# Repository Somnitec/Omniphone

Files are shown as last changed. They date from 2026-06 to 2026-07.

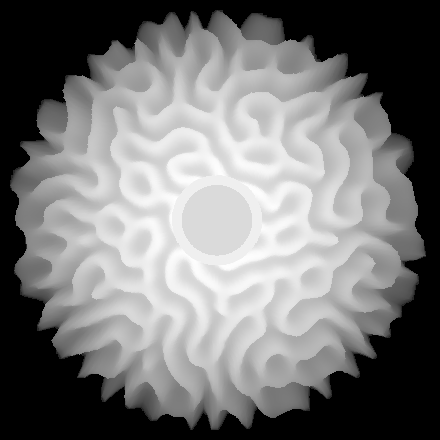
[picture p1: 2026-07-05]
3d-model/preview_flat_dome.png

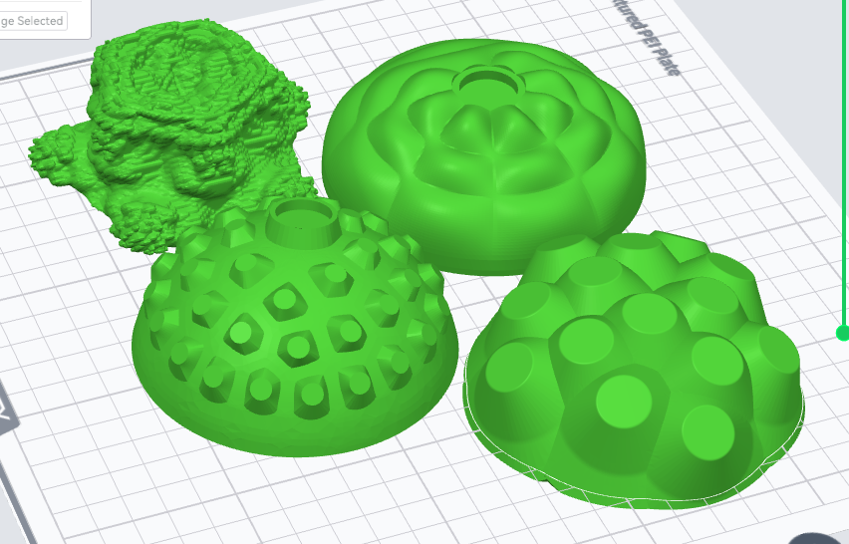
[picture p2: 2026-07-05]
3d-model/some first iterations.png

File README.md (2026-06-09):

# ◉ Omniphone
 
> *An instrument for everyone. Any shape. Any sound. Any player.*
 
---
 
The **Omniphone** is an open, tactile electronic instrument — built to be as expressive for a seasoned performer as it is immediate and joyful for someone touching it for the first time.
 
It started as a single idea. It grew into a collaboration. Now it's becoming a platform.
 
---
 
## ✦ Origin
 
The Omniphone was conceived and first built by **Arvid Jense**, as an experiment in what an electronic instrument could be if it didn't assume what a musician looks like.
 
It was developed further in close creative partnership with **Marie Caye** — shaping its philosophy of radical accessibility and shape language.
 
→ *Read the origin story and the thinking behind inclusive instrument design on [Create Digital Music](https://cdm.link/omniphone-inclusive-design-music-therapy/)*
 
---
 
## ✦ Now
 
The project continues under **Arvid Jense**, in active collaboration with **[SoundLab at Muziekgebouw aan 't IJ](https://www.muziekgebouw.nl)**.
 
This phase is about turning the Omniphone from a singular instrument into a **flexible platform**:
 
- 🔷 **Many shapes** — modular physical configurations for different bodies, contexts, and settings
- 🔊 **Many sounds** — a sonic engine that adapts to the musical world of each player
- 🎓 **Many players** — from children in workshops to professional performers on stage; from music therapists to noise artists
 
---
 
## ✦ What It Is
 
The Omniphone uses **capacitive touch sensing** to turn almost any surface into a playable instrument. No keys. No buttons. No prior musical knowledge required.
 
It is simultaneously:
- A **workshop instrument** — robust, inviting, immediately rewarding
- A **performance instrument** — expressive, precise, deeply configurable
- A **research platform** — for inclusive design, music therapy, and expanded musical interfaces
 
---
 
## ✦ Status
 
> 🚧 **Active development** — hardware and software in flux
 
Current focus:
- Capacitive sensing via MPR121
- LED feedback and expressive output mapping
- Platform architecture for multi-configuration support
 
---
 
## ✦ Code & Building

The firmware is a **PlatformIO monorepo**: every hardware configuration ("variant") lives in its own folder under [`variants/`](variants/) and is selected by a matching `[env:…]` in [`platformio.ini`](platformio.ini). Shared libraries (MPR121 driver, LCD driver) live in [`lib/`](lib/) and compile into every build; bring-up/diagnostic sketches live in [`test/`](test/).

### Variants

| `pio run -e …` | Board | Pads | Sensor | Audio | Notes |
|---|---|:----:|---|---|---|
| `pico-13pad` *(default)* | RPi Pico / RP2040 | 13 | MPR121 | Mozzi (I²S) | earlephilhower core |
| `esp32s3-19pad` | ESP32-S3 (LilyGO T8-S3) | 19 | 4× MPR121 | TBD | WiFi/OTA — capsense bring-up test (Teleplot + web view) |
| `teensy40-11pad` | Teensy 4.0  | 11 | MPR121 | Teensy Audio | original firmware |
| `teensy40-12pad-screen`  | Teensy 4.0  | 12 | MPR121 | Teensy Audio | + 1.28" round LCD |
| `teensy32-13pad` | Teensy 3.2  | 13 | MPR121 | Teensy Audio | ⚠ WIP — uses a Teensy-4 USB register, won't build for 3.2 yet |
| `teensy-lc-7voice` | Teensy LC | 7 | TSI | internal DAC | standalone; WS2812 + PWM LEDs |

```bash
pio run -e pico-13pad              # build
pio run -e pico-13pad -t upload    # build + flash
```

### Working on / adding a variant

- **Each instrument is a folder, not a branch.** To work on one, edit its folder in `variants/` directly on `main`. To freeze a finished instrument, **tag a release** rather than parking a branch.
- **Backporting** improvements is just editing shared code in `lib/` — every variant picks it up. (Variant-specific code that proves reusable can be promoted into `lib/` over time.)
- **New variant:** copy the closest `variants/<x>/` folder, adjust its `config.h` (pin map / pad count / layout), and add a `[env:…]` pointing `build_src_filter` at the new folder.
- **Branches** are for in-progress features/experiments that merge back into `main`.

---

## ✦ Contributing
 
This repository is the working codebase for the Omniphone platform. Development is led by Arvid Jense with SoundLab at Muziekgebouw aan 't IJ.
 
If you're a developer, instrument builder, music therapist, or curious human — get in touch before diving in.
 
---
 
## ✦ Credits
 
| Role | Person |
|---|---|
| Concept & original design | Arvid Jense |
| Co-development | Arvid Jense & Marie Caye |
| Ongoing development | Arvid Jense |
| Institutional partner | SoundLab, Muziekgebouw aan 't IJ |
 
---
 
*The Omniphone exists because music shouldn't have gatekeepers.*

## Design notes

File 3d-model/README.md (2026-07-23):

# 3d-model — enclosures

Procedural generators for Omniphone enclosures, each paired with a live
browser viewer (three.js, vendored offline) that emits a copy-pasteable
parameter block:

> **Blender port (in progress):** [`blender/omniphone_sculptor.py`](blender/omniphone_sculptor.py)
> is moving the *whole* modelling workflow into Blender (replacing the
> sculptor.html → Fusion 360 hand-off). Done so far: ball → squish →
> gradient-flatten underside → **screen platform + USB/jack panel flats**
> (disc attractors: settable tilt/azimuth/Ø/height, merge reach & strength;
> circle-empty markers carry the axes for the aperture slice) → N pad seeds
> (phyllotaxis / random / Lloyd, repelled from the screen cone) → Gray-Scott
> brain coral grown **on the mesh graph** (no pole distortion), ridges out /
> grooves in, coverage fade, auto-masked off the facets. Watertight, mm units.
>
> - **Live editing:** shape/displacement sliders update **while dragging**
>   (~5 ms; the coral field rides along stably). Pad/coral/RD changes make the
>   pattern visibly **re-grow in the viewport** (~5 fps chunks, settling in a
>   couple of seconds at the exact final state). Toggle with *Auto update*;
>   *Generate* always forces a full clean rebuild.
> - **Facet orientation:** screen/port discs lie **tangent to the smooth body
>   surface** by default (tilt/azimuth choose *where*, like a spoke); a *Pitch*
>   slider rotates the face off the tangent in the azimuth plane.
> - **Build step (slice 3):** the **Build Shell + Plate** button (section 6)
>   runs the engineering pass on the current body: flat bottom cut → plate
>   recess (2 mm in / 4 mm inset rabbet, solid lip) → ~3 mm hollow shell →
>   1.28″ screen counterbore + through-aperture, USB/jack holes → 3× M3
>   self-tap bosses on solid pads → a countersunk bottom plate that drops in
>   flush, with a **key ridge** tracing the lip/boss-pad profile so it can't
>   slide or rotate. ~30 s; output is two closed manifolds, checked per boolean
>   step in the console. The screen gets the real 1.28″ pocket: Ø36 aperture
>   lip (0.5) → Ø39 drop-in pocket with a truncated tab-corner cutout (starts
>   2.5 mm behind the lip, capped at the platform edge so it never holes the
>   visible shoulder) + four heat-stake prongs at the square-tangent points.
>   **Plate outfit** (panel 7, live ~0.3 s once a shell exists): dome legs
>   (count/Ø/height/splay/radius, flat feet sized for stick-on pads), a
>   speaker bay (recess + through-firing opening w/ rim), transducer glue zone
>   w/ optional thinning, PAM8403 recess + melt posts, DPST switch hole + Ø1
>   melt rivets @15 mm, battery corral (walls + strap gaps — no prongs against
>   a LiPo). The speaker bay is **round by default** (recess + through-opening
>   + meltable lock ridge around the rim) with the rectangular box bay as the
>   alternate type. Pad layouts gained **Even (max spacing)** — relaxation run
>   to convergence → most-equal pad sizes; pad count goes to 96.
>   **Layer stack** (three stackable passes, any combination): panel 1 picks
>   the **Form** — *Squished ball* · *Puffed Voronoi cells* (one cell per pad,
>   Even layout ⇒ equal pads) · *Crystal/faceted* (every pad becomes a flat
>   facet + a crown facet under the screen; filler facets close the underside)
>   · *Cymatics dome* (Bessel standing wave) · *Mandelbulb* (radially-captured
>   fractal, ~1 s per slider change, cached otherwise). Panel 2 = pad count &
>   layout (greyed out when nothing uses pads). Panel 3 = the form's settings.
>   Panel 4 = the **Texture pass**: a second algorithm displaced over the
>   shaped surface with its own feature count/seed/amount, decoupled from the
>   pads — Voronoi cells (grooves scale with cell size), Crystal facets (a
>   *gem grinder*: the crest inside each texture cell is cut flat — sharp
>   planar chips), Cymatics ripple, or Mandelbulb crust. Panel 5 = **Brain
>   coral** (header toggle), the RD relief grown on top; pads are its seeds.
>   So *cells + crystal texture*, *cymatics + coral*, *coral + small cells*,
>   or the same algorithm twice at two scales all compose. Only the coral
>   costs sim time — when it's off, no RD ever runs and everything is instant.
>   If the screen cutter `blender/screencutout.stl` exists it is
>   used verbatim (scaled to mm, centred on its top-lip circle, depth/bore/tab
>   re-measured from the file on every build); prongs and boss stay parametric.
>   [`screen_pocket_test.stl`](screen_pocket_test.stl) is a cut-out puck of
>   just the screen pocket for fit-testing (print it screen-face down).
>   ⚠ Don't reinstall the addon via the Add-ons menu — Install *copies* the
>   file, replacing the repo symlink, and edits stop arriving. Use the 🔌
>   Reload button (or restore the symlink). *Bottom cut* is mm above the resting plane (z=0) and
>   shows as a live wire circle in the viewport while you drag. Port *Pitch* is
>   absolute (0° = face perpendicular to the ground); the screen's is relative
>   to the surface tangent. Coral changes compute in the background and show
>   the finished shape by default — flip *Grow in viewport* on to watch the
>   pattern grow instead. Ridge height / groove depth accept negative values
>   (dented ridges, bulging grooves). Implementation notes: the offset cavity is voxel-remeshed
>   (its self-intersections in tight concave regions otherwise poison every
>   later boolean), the lip is carved *out of the cavity tool* so the delicate
>   underside resolves in a single subtraction, and everything runs on 4.5's
>   manifold solver (the exact solver misclassified the large hollowed shell).
> - **Install:** Blender ≥ 4.2 (4.5+ recommended for the manifold solver) →
>   Edit ▸ Preferences ▸ Add-ons ▸ Install… → pick the file → enable. Panel:
>   3D view sidebar (N) → **Omniphone** tab. Hit **Generate Omniphone**; the
>   🔄 button rolls a new random instrument. The installed addon is a symlink
>   to this repo file; after edits press the 🔌 **Reload** button in the panel
>   header — it re-reads the file and re-registers in place (slider values
>   survive). More reliable than F3 → "Reload Scripts" in 4.5.
> - **Headless check:** `blender -b --factory-startup --python-exit-code 1
>   --python blender/omniphone_sculptor.py -- --selftest`
> - **Roadmap** (next slices): parametric PCB-holder placeholder trimmed to the
>   shell interior; pad flat seats/recesses; more pad algorithms after coral.
> - **Known rough edges:** port flats low on the body sit on the rounded floor
>   rim and look grafted-on — keep `height − Ø/2 ≳ 8 mm` (Generate warns) and
>   tune Merge reach/strength by eye. Wall thickness is `wall` ± half the
>   0.8 mm cavity voxel. The USB hole is a plain round hole — size it to the
>   panel-mount part you pick.

> **Start here for exploring shapes:** [`sculptor.html`](sculptor.html) is a
> unified playground — one page, ~24 shapes in a dropdown grouped by family:
> **Classic** (thistle, Lloyd-relaxed thistle, cymatics, mandelbulb),
> **Coral** (brain-coral/RD, bubble, cauliflower, great-star),
> **Cactus**, **Mushroom**, **Fractals** (mandelbox, quaternion-Julia,
> juliabulb, Menger sponge, Sierpiński tetra, Apollonian packing, fBm blob,
> romanesco), and natural-shape *algorithms* (metaball lobes ≈ the real device,
> puffed Voronoi cells, pollen/geodesic bumps, gourd lobing, superformula,
> crystal facets). Shared knobs (size, feature count, screen) persist as you
> switch shapes; shape-specific knobs swap in/out. Every shape is one connected
> shell you can wall-hollow, with distinct convex touch pads.
>
> - **★ Save current** stores the shape + all its params as a named **favourite**
>   (browser localStorage); reload it any time from the *Saved* dropdown, or 🗑 delete it.
> - **Copy params** emits the settings; **⬇ Download STL** exports the current
>   shape from the browser (binary STL, z-up, base down).
>
> The per-family `.py` scripts below remain the higher-fidelity source for
> production STLs (the fractal/algorithm families are viewer-only for now).

| Generator | Viewer | Shape |
|---|---|---|
| [`thistle.py`](thistle.py) | [`viewer.html`](viewer.html) | thistle-flower bulb with phyllotaxis needles |
| [`thistle_lloyd.py`](thistle_lloyd.py) | [`viewer_lloyd.html`](viewer_lloyd.html) | same bulb, needles spread by **Lloyd's relaxation** (organic teasel/burr) |
| [`cymatics.py`](cymatics.py) | [`cymatics.html`](cymatics.html) | dome sculpted by a cymatics standing-wave field |
| [`mandelbulb.py`](mandelbulb.py) | [`mandelbulb.html`](mandelbulb.html) | simplified power-8 Mandelbulb fractal solid |
| [`coral.py`](coral.py) | [`coral.html`](coral.html) | coral body grown by a **reaction-diffusion** field; three forms |

> **Note (venv):** the local `.venv` was built against Python 3.13; a system
> upgrade to 3.14 orphaned it, so `build123d` (used by `thistle.py` and
> `thistle_lloyd.py`) currently won't import. Rebuild it with `./setup.sh`
> before running those two. `cymatics.py` and `mandelbulb.py` are pure standard
> library and run under any `python3` with no venv. `coral.py` needs only
> **numpy** (already installed system-wide — `python3 coral.py`, no venv).

---

## thistle-bulb enclosure

Procedural generator for the Omniphone thistle-flower enclosure: an ellipsoid
bulb with a flat, rounded base, a screen recess in the top, and N spikes
("needles") in a sunflower / golden-angle pattern. Each needle carries copper
tape for capacitive sensing.

## Setup (Fedora)

```bash
python3 -m venv ~/cad && source ~/cad/bin/activate
pip install build123d          # pulls OpenCASCADE bindings (~few hundred MB, once)
```

## Interactive preview (sliders, real-time)

Open [`viewer.html`](viewer.html) in a browser (double-click, or right-click →
"Open with Live Server" in VS Code). Drag the sliders to reshape the bulb and
needles in real time, orbit with the mouse, then hit **Copy params** and paste
the block into [`thistle.py`](thistle.py) to generate the real solid.

The preview is a fast, faithful approximation: needle cones simply *overlap* the
bulb instead of being boolean-unioned, and rim fillets aren't shown — those only
happen in the real build123d export. three.js is vendored in `vendor/` so it
works offline.

## Generate the real model

```bash
cd 3d-model
python thistle.py              # -> thistle.step + thistle.stl
```

## Files

| File | Use |
|---|-----|
| `thistle.step` | Open/edit in **Fusion 360** or **FreeCAD** — imports as an editable solid. Do shell/wall thickness, mounting bosses, and the exact screen bezel here. |
| `thistle.stl`  | Send straight to the slicer / printer. |

`sudo dnf install freecad` gives you a native STEP viewer on Fedora for quick
iteration before touching Fusion 360.

## Tuning

Every dimension is a variable at the top of [`thistle.py`](thistle.py):

- **Size / elongation** — `BULB_RADIUS`, `BULB_HEIGHT` (target envelope ~ 220 × 220 × 100 mm)
- **Flat cuts + rounding** — `TOP_CUT_FRAC`, `BOT_CUT_FRAC`, `RIM_FILLET_TOP`, `RIM_FILLET_BOT`
- **Screen** — `SCREEN_MODE` (`"bulb"` = recess in the top, `"needle"` = the screen
  rides on one of the phyllotaxis needles), `SCREEN_DIA`, `SCREEN_MARGIN` (ring of
  material around the screen), `SCREEN_DEPTH`, `SCREEN_NEEDLE_LEN`, and
  `SCREEN_NEEDLE_IDX` (which needle carries it, counted from the top; 0 = topmost).
  In `"needle"` mode the band automatically extends to the pole (`BAND_HIGH` is forced
  to 1 and greyed out in the viewer). `SCREEN_DIA = 0` disables the screen entirely.
- **Needles** — `N_NEEDLES`, `NEEDLE_BASE_DIA`, `NEEDLE_LEN`, `NEEDLE_TIP_DIA`, `BAND_LOW`, `BAND_HIGH`
- **Needle size ramp** — `NEEDLE_SIZE_START` / `NEEDLE_SIZE_END` scale each needle's
  diameter linearly from the first to the last (e.g. 1.0 → 1.6 makes them fatten toward the end).
- **Needle fillets** — flat tips with a settable edge fillet (`NEEDLE_TIP_FILLET`), a
  concave foot blending into the bulb (`NEEDLE_BASE_FILLET`), and a merge flare so
  neighbouring needles fuse when they touch (`NEEDLE_MERGE_FILLET`). `NEEDLE_EMBED`
  sets how far each foot protrudes into the bulb.

`viewer.html` shows the live W × D × H envelope and its number fields accept typed
values, so you can dial the enclosure straight to 220 × 220 × 100 mm.

## Notes / next steps

- The print is currently a **solid**. Shell it (hollow wall + electronics
  cavity) in Fusion after import, or add it to the script.
- Spikes point straight out along the surface normal; a real thistle sweeps
  them up toward the crown — a small tweak (blend normal with +Z) if wanted.
- Needle tips are now flat (with a settable `NEEDLE_TIP_FILLET`), so copper tape
  seats on a real pad. Consider a keep-out ring around the screen hole so no
  spike intrudes on the bezel.
- The needle-to-needle *merge* is geometric (flared, coved feet), not a true CAD
  fillet — OpenCASCADE won't fillet all ~200 mutual seams in one pass. For a crisp
  blend, import the STEP into Fusion 360 and run one Fillet/Blend on the fused base.

---

## thistle (Lloyd-relaxed) — organic spike spread

[`thistle_lloyd.py`](thistle_lloyd.py) is `thistle.py` with **one thing changed**:
the needles are positioned by **Lloyd's relaxation** (a centroidal Voronoi
relaxation) instead of the golden-angle phyllotaxis spiral. Random seed points on
the bulb's surface band are repeatedly nudged to the centroid of their Voronoi
cell, so they settle into an *even but non-lattice, organic* spacing — the look of
a real teasel / burr head rather than a machined sunflower. Everything else (bulb,
needle profile, fillets, screen options, STEP/STL export) is identical to
`thistle.py`, so re-read its tuning notes above; they all apply.

```bash
cd 3d-model
./setup.sh                     # first, if the venv is orphaned (see note at top)
.venv/bin/python thistle_lloyd.py   # -> thistle_lloyd.step + thistle_lloyd.stl
```

Extra parameters (on top of every `thistle.py` knob):

- **`RELAX_ITERS`** — number of relaxation passes. More = more even; `0` = the raw
  random start (clumpy). ~15+ is fully settled.
- **`RELAX_SEED`** — RNG seed. Change it to reshuffle into a *different* organic
  arrangement; the result is fully reproducible per seed.
- **`RELAX_SAMPLES`** — Monte-Carlo samples used to estimate each Voronoi centroid
  (higher = smoother relaxation, slower).

**Screen** is supported exactly as in `thistle.py`: `SCREEN_MODE = "bulb"` (recess
in the top) or `"needle"` (the screen rides the *top-most* relaxed spike).

*Boundary note:* Lloyd's relaxation naturally pulls points ~0.1 (in height
fraction) away from the band edges, so spikes don't quite reach `BAND_LOW`. Lower
`BAND_LOW` a touch if you want them further down.

---

## mandelbulb — simplified fractal solid

[`mandelbulb.py`](mandelbulb.py) generates the iconic **power-8 Mandelbulb** as a
watertight solid, taken at a **low iteration count** so it comes out as a smooth,
rounded, lobed blank you can actually print and machine features into — not an
un-printable, infinitely crenellated fractal. Pure standard library, no venv.

```bash
cd 3d-model
python3 mandelbulb.py          # -> mandelbulb.stl   (~3 s at GRID=96)
```

**Editing in Fusion 360.** The output is a **mesh** (the fractal has no clean BREP
form), so import `mandelbulb.stl` as a *mesh body*, then:

- add the **screen pocket** and **power/USB cutouts** as parametric solids and
  `Combine`/subtract them, or use the built-in `SCREEN_MODE = "bulb"` recess (see
  below) as a starting seat;
- `Mesh → Convert Mesh → Faceted/Prismatic` to get a BRep if you need one — or drop
  `GRID` (fewer triangles: 96 ≈ 193 k tris; 64 ≈ 85 k) to stay under Fusion's
  mesh-conversion limits;
- `Mesh → Reduce` also thins the triangle count for easier editing.

The surface is extracted with **marching tetrahedra**, which guarantees a
watertight, manifold mesh (the script prints a `WATERTIGHT` check on every run).

Key parameters:

- **`POWER`** — fractal order (8 = the classic Mandelbulb).
- **`ITERATIONS`** — escape depth. **Low = smooth simplified blob; high = fractal
  crust.** This is the main "simplify" dial.
- **`LEVEL`** — iso-surface threshold. Lower = puffier/rounder; higher (toward
  `ITERATIONS`) = tighter with more surface detail.
- **`GRID`** — samples per axis (64 quick, 96 good, 128+ fine/slow). Sets mesh
  density.
- **`SIZE_MM`** — scales the finished solid so its largest span is this many mm.
- **`BOX`** — half-width of the sampling box (fractal units). Must clear the
  iso-surface's natural radius on every side, or the shape gets clipped flat by
  the box wall.
- **`FLATTEN_ALL`** / **`FLATTEN_BASE`** / **`FLATTEN_ZONE`** — vertical squash for
  a standable base, applied as a smooth post-process warp (not a cutting plane) so
  the surface stays one continuous skin. `FLATTEN_ALL` compresses the whole shape;
  `FLATTEN_BASE` adds extra compression near the bottom pole, ramped in over the
  bottom `FLATTEN_ZONE` fraction of the lower half.
- **`SMOOTH_ITERS`** — Laplacian smoothing passes to soften the tetra faceting.
- **Screen** — `SCREEN_MODE = "bulb"` + `SCREEN_DIA` / `SCREEN_DEPTH` carves a round
  flat recess into the top lobe (voxel-resolution — raise `GRID` for crisper walls,
  or true it up in Fusion). `"none"` leaves the raw bulb for you to cut the screen
  and connectors in Fusion, which is the more flexible route.

Dial `POWER` / `ITERATIONS` / `LEVEL` live in [`mandelbulb.html`](mandelbulb.html)
(a raymarched preview), then **Copy params** into the script.

---

## coral — reaction-diffusion enclosure

[`coral.py`](coral.py) grows a coral-like body from a **Gray-Scott
reaction-diffusion** field — the same maths behind the labyrinthine ridges of
brain coral and Turing patterns generally. The simulation is **seeded at the pad
centres**, so the wavy ridges radiate out from every pad (RD *grows* the
protrusions) while the same field displaces the whole surface into coral grooves
(RD *textures* it). Each of the `N_PADS` "loops" is a raised, **flat-topped seat**
sized for copper tape.

```bash
cd 3d-model
python3 coral.py               # -> coral.stl   (~2 s; needs numpy, no venv)
```

Output is a mesh STL — import into Fusion 360 / FreeCAD as a **mesh body** (like
`mandelbulb.stl`) and shell it / add connector cutouts there. A STEP path can
follow later.

**Three forms**, all from the one script — set `FORM`:

| `FORM` | Look |
|---|---|
| `"dome"` (default) | a low **brain-coral dome** carpeted in ridges; pads are flat seats raised on the bumps. One continuous watertight mesh. |
| `"bulb"` | an ellipsoid body (thistle-style) with `N_PADS` **wavy coral branches** = pads. |
| `"fingers"` | a base plate with `N_PADS` **upright wavy finger-coral tubes** = pads. |

For `bulb` / `fingers` the branches are separate watertight solids that *overlap*
the body (the slicer / Fusion unions them on import) — the same trick as thistle's
needles.

Key parameters:

- **Pads ("loops")** — `N_PADS` (= your electrode count), `PAD_DIA` (flat seat
  size), `PAD_HEIGHT` (how far each protrusion rises — the "length"), `PAD_SKIRT`
  (blend back to the body), `PAD_BAND_LO` / `PAD_BAND_HI` (keep pads off the
  rim/pole), `PAD_LAYOUT` (`"phyllotaxis"` or `"ring"`).
- **`PAD_STYLE`** (dome only) — `"raised"` puts a flat copper seat on a bump per
  pad; `"flat"` gives a **pure brain-coral dome** with no raised seats — the
  surface is unbroken ridges and the pads are just marked positions (RD still
  seeds them, so you get N organized coral zones — stick the copper on the ridges).
- **Coral pattern** — `RD_AMOUNT` (ridge height in mm; `0` = smooth body + bare
  pads), `RD_FEED` / `RD_KILL` (the pattern character — presets in the script
  header: coral/worms/spots/maze/mitosis), `RD_STEPS` / `RD_GRID` (sim
  quality/speed), `RD_SEED` (reshuffle into a different coral), `RD_RECTIFY`
  (`"signed"` ridges+grooves vs `"absolute"` all-positive welts).
- **Broken ridges** — `RIDGE_BREAK` (`0` = continuous coral, higher chops the
  ridges into segments), `RIDGE_LENGTH` (approximate segment / loop length in mm),
  `RIDGE_WIGGLE` (`0` = smooth, higher makes the ridges meander / wiggle). These
  are a cheap post-process on the field — in the viewer they update instantly
  without re-running the simulation, and they apply to all three forms.
- **Body** — `BODY_RADIUS`, `BODY_HEIGHT`, `DOME_PROFILE` (`ellipse` / `parabola`
  / `cosine` / `flat`), `BULB_BOT_CUT` (bulb stand), `PLATE_HEIGHT` (fingers base).
- **Screen** — `SCREEN_MODE = "center"` (round recess in the top), `"pad"` (recess
  carved into pad `SCREEN_PAD_IDX`), or `"none"`; `SCREEN_DIA` / `SCREEN_MARGIN` /
  `SCREEN_DEPTH`.

Print is a **solid** — hollow it after import, like the others.

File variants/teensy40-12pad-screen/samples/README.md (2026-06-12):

# Samples (Grain Hang + Strings modes)

The wavs in this folder get baked into the Teensy's flash. **The current files are
synthesized placeholders — replace them with real recordings for the good stuff.**

## How to swap a sound
1. Drop your replacement wav here, keeping the naming convention
   `<name>_<rootHz>.wav` — the firmware needs `hang_*.wav` and `strings_*.wav`:
   - `hang_146.83.wav` → one clean handpan/hang strike, the number = its pitch in Hz
   - `strings_130.67.wav` → a sustained string-section note that loops cleanly
2. Delete the old file (only one of each name prefix may exist).
3. Run `python3 tools/wav2header.py` from the repo root.
4. Rebuild + upload.

## Guidelines
- Mono 16-bit 44100 Hz is ideal (stereo gets downmixed, other rates are handled).
- Keep it short: a hang strike 2–4 s, a string loop 1–3 s. Flash budget is ~1.9 MB
  total; the converter prints sizes.
- The **root Hz in the filename must match the recorded pitch** or every pad will
  play out of tune. (A4=440 reference: D3=146.83, C3=130.81, A3=220 …)
- Strings: trim to a clean loop (no attack, no fade) — the engine loops the whole
  file. The hang strike should include its attack.

## Where to find good ones (CC0 / free)
- freesound.org — search "handpan single note", "hang drum D3", "string ensemble
  sustain C3"; filter by license CC0.
- philharmonia.co.uk/explore/sound_samples — free orchestral single notes.
- vis.versilstudios.com (VSCO2 CE) — public-domain orchestral samples.

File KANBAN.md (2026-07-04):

# Omniphone Kanban & Status Board

Single comprehensive file: all tasks, per-instrument status, and experimental lines.

---

## Quick Reference: Instruments & Experimental Lines

### Instruments by Shell

| Shell | Board | Pads | Status | Active Work | Next |
|---|---|---|---|---|---|
| 🎋 Bamboo 12-pad screen | Teensy 4.0 | 12 | **🔥 In Progress** | Sensor tuning, harmonic journey | Test with speaker? |
| ⚫ Black 11-pad | Teensy 4.0 | 11 | ⏸ Backlog | Replace board decision | Decide: Pico or ESP32? |
| ⚫ Black 13-pad | Pico | 13 | 📋 Todo | Get cap-touch resistors | Test tuning |
| ⚪ White 7-pad | Teensy LC | 7 | 📋 Todo | Test pad LEDs | Verify feasibility |
| ⚪ White 19-pad screen | ESP32-S3 | 19 | 📋 Todo | Sound design options | Implement granular? |
| 🎵 ESP32 Audio Kit | ESP32-S3 | ? | 📋 Todo | Max voice count test, case design | Finalize audio engine |
| ✨ Textured white shell | Pico | 13 | 📋 Todo | Install + cap-sense tuning | Screen parity? |
| 🛡️ Teensy 3.2 + Shield | Teensy 3.2 | 13+ | 📋 Todo | Speaker + enclosure design | CAD finalize |
| 🪵 Printed wooden 12-pad screen | TBD | 12 | ⏸ Backlog | Screen fit, board choice | Architecture decision |

### Experimental Lines (Cross-Cutting)

| Line | Instruments | Status | Next |
|---|---|---|---|
| 🔊 **Speaker Design** | Teensy 3.2 + Shield, ESP32 Audio Kit | Design phase | Sketch enclosures, test drivers |
| 📍 **Pico Cap-Sense Tuning** | Black 13-pad, Textured white | 🔌 Resistors pending | Install + tune, compare vs MPR121 |
| 🎛️ **ESP32-S3 Native Touch** | Black 13-pad, White 19-pad | Design phase | Validate on black-13pad first |
| 🎹 **Many-Pad MPR121** | Teensy 4.0 (future) | Planned | Awaits board consolidation |
| 🥁 **Hang Drum Sound Design** | All (primary: Bamboo, White 19-pad, Audio Kit) | Early | Test on multiple boards, refine timbre |

---

## 🔥 In Progress

### Bamboo 12-Pad Screen (Teensy 4.0)
**Board:** Teensy 4.0 | **Pads:** 12 (MPR121) | **Screen:** 1.28" LCD  
**Epics:** Hang drum sound design

**Current Work:**
- Tweak MPR121 sensor code — Refine `PROX_DEADBAND`, `PROX_ATTACK_K`, `PROX_RELEASE_K` tuning. [config.h](variants/teensy40-12pad-screen/config.h) | [firmware](variants/teensy40-12pad-screen/teensy40-12pad-screen.cpp)
- Harmonic journey sound design — Sample playback + timbre morphing on screen. [sample_data.h](variants/teensy40-12pad-screen/sample_data.h)

**Build & Flash:**
```bash
pio run -e teensy40-12pad-screen -t upload
pio device monitor -e teensy40-12pad-screen
```

**Next Steps:**
- [ ] Finalize sensor tuning on bamboo shell
- [ ] Test harmonic journey with samples
- [ ] Evaluate hang drum sound for other shells
- [ ] Consider speaker add-on

---

## 📋 Todo

### Black 13-Pad (Pico) — Cap-Sense Validation
**Board:** Pico (RP2040) | **Pads:** 13 (bare-pin PIO cap-sense, no MPR121)  
**Epics:** Pico cap-sense tuning, ESP32-S3 native touch (comparison)  
**Status:** 🔌 Hardware pending (resistors ordered)

**Current Work:**
- Get resistors for cap-touch — Procure ~1M resistors (exact value TBD). [config.h](variants/pico-13pad/config.h) | Memory: [[Pico PIO capsense]] Mode 3 PIO guarded scan
- Install Pico + tune cap-sense — Install in shell, refine CDC/CDT on resistive surface. Measure latency vs MPR121.
- Test on textured surfaces — Validate consistency across shell texture variations.

**Build & Flash:**
```bash
pio run -e pico-13pad -t upload
pio device monitor -e pico-13pad
```

**Next Steps:**
- [ ] Procure 1M resistors
- [ ] Install Pico in black-13pad shell
- [ ] Tune CDC/CDT on resistive surface
- [ ] Measure latency (touch → ADC)
- [ ] Compare vs MPR121 baseline + ESP32-S3 native
- [ ] Document final tuning in config.h

---

### White 7-Pad (Teensy LC) — LED Testing
**Board:** Teensy LC | **Pads:** 7 (TSI capacitive touch, internal DAC)  
**Epics:** —

**Current Work:**
- Test pad LEDs — Investigate GPIO availability for LED control. Check conflict with TSI scanner. [config.h](variants/teensy-lc-7voice/config.h) | Memory: [[Teensy LC 7-voice build]]

**Build & Flash:**
```bash
pio run -e teensy-lc-7voice -t upload
pio device monitor -e teensy-lc-7voice
```

**Next Steps:**
- [ ] Test LED control on available GPIO
- [ ] Verify LED brightness doesn't interfere with TSI
- [ ] Document GPIO allocation in config.h
- [ ] Prototype LED feedback (brightness = proximity)

**Notes:**
- Pins 15/23 side of board known electrically noisy
- Simplest variant: no I²C, no I²S, just TSI + DAC

---

### White 19-Pad Screen (ESP32-S3) — Sound Design
**Board:** ESP32-S3 | **Pads:** 19 (MPR121 I²C) | **Screen:** 1.28" LCD  
**Audio:** I²S DMA to DAC, dual-core (Core 0=sensing, Core 1=audio)  
**Epics:** Hang drum sound design, ESP32-S3 native touch (future alternative)

**Current Work:**
- Implement other sound design options — Explore granular, wavetable morphing, FM, sample playback. [firmware](variants/esp32s3-19pad/esp32s3-19pad.cpp) | [config.h](variants/esp32s3-19pad/config.h)
- Touch-responsive timbre control — Screen UI for parameter tweaking.

**Build & Flash:**
```bash
pio run -e esp32s3-19pad -t upload
pio device monitor -e esp32s3-19pad
# OTA (WiFi): OMNIPHONE_OTA_PASSWORD=<pwd> pio run -e esp32s3-19pad-ota -t upload
```

**Next Steps:**
- [ ] Decide on primary sound engine (granular vs FM vs wavetable)
- [ ] Implement + test selected option
- [ ] Compare hang drum character to Bamboo
- [ ] Iterate timbre library
- [ ] Evaluate native touch as MPR121 alternative (future)

**Notes:**
- High-end variant: dual-core, screen, WiFi-capable, OTA updates
- I²S DMA = smooth polyphony, good CPU headroom

---

### ESP32 Audio Kit — Granular Synthesis & Case Design
**Board:** ESP32-S3 on Audio Kit carrier | **Codec:** ES8388 (professional audio) | **PSRAM:** 8MB  
**Pads:** Native touch (14 max) or MPR121 (experimental)  
**Epics:** Hang drum sound design (granular), speaker design (secondary)

**Current Work:**
- Test max granular voices — Determine polyphony limit; profile CPU + memory; measure latency. [config.h](variants/esp32audiokit-sampling/config.h) | Memory: [[ESP32 Audio Kit sampler]]
- Design printable case — CAD enclosure for Audio Kit + pad layout. Account for screen (future), audio I/O access.

**Build & Flash:**
```bash
pio run -e esp32audiokit-sampling -t upload
pio device monitor -e esp32audiokit-sampling
```

**Hardware:**
- ES8388 codec: Balanced XLR out + headphone jack
- 8MB PSRAM: ~45 sec mono / ~22 sec stereo at 44.1 kHz
- I²S: Full-duplex capable
- Native touch: 14 channels on-chip

**Next Steps:**
- [ ] Set up granular synthesis engine (Karplus-Strong or sample playback)
- [ ] Measure voice count at various buffer sizes
- [ ] Profile CPU (FreeRTOS task priority, Core allocation)
- [ ] Test latency with multiple voices
- [ ] Finalize voice ceiling
- [ ] Sketch case design (I/O access, thermal)
- [ ] CAD printable enclosure

**Notes:**
- Audio quality champion: professional codec, balanced out, low noise
- Granular + sample storage = strong differentiation
- Could become standalone sampler/synth product

---

### Textured White Shell (Pico) — Cap-Sense Tuning & Screen Parity
**Board:** Pico (RP2040) | **Pads:** 13 (bare-pin PIO cap-sense)  
**Epics:** Pico cap-sense tuning, screen parity decision

**Current Work:**
- Attach Pico + tune cap-sense — Install in shell, refine CDC/CDT tuning. Test on textured surface (may affect baseline). Validate LED performance.
- Screen parity decision — Can Pico + screen match ESP32-S3 features? Research screen driver compatibility with PIO cap-sense.

**Next Steps:**
- [ ] Install Pico in shell
- [ ] Tune cap-sense on textured surface
- [ ] Research screen + I2C compatibility with PIO
- [ ] Decide: add screen or keep bare?
- [ ] Test feature/UX parity if screen added

**Notes:**
- Surface texture may affect capacitance baseline; plan for retrim
- GPIO constraints if screen added (I2C/SPI conflicts possible)

---

### Teensy 3.2 + Audio Shield — Speaker Design & Enclosure
**Board:** Teensy 3.2 + Audio Shield | **Pads:** 13 (MPR121)  
**Audio:** I2S to Audio Shield codec  
**Epics:** Speaker design (primary focus)

**Current Work:**
- Speaker design + enclosure — Acoustic principles (driver impedance, ports, resonance). CAD design for integrated speaker. [config.h](variants/teensy32-13pad/config.h) | [firmware](variants/teensy32-13pad/teensy32-13pad.cpp)

**Build & Flash:**
```bash
pio run -e teensy32-13pad -t upload
pio device monitor -e teensy32-13pad
```

**Next Steps:**
- [ ] Sketch speaker + enclosure designs (ported vs sealed)
- [ ] Research compact driver options (2–4")
- [ ] CAD prototype mount for driver
- [ ] Test acoustic response
- [ ] Finalize enclosure design
- [ ] 3D print + assemble prototype

**Notes:**
- Teensy 3.2 retired from primary variants; repurposed for speaker focus
- Audio Shield codec = clean audio path
- 13 pads good for hand-held + integrated speaker
- Could be "Omniphone portable speaker variant"

---

## ⏸ Backlog (Waiting on Decisions)

### Black 11-Pad (Teensy 4.0) — Board Replacement Decision
**Board:** Teensy 4.0 | **Pads:** 11 (MPR121)  
**Status:** Awaiting architecture decision

**Decision Point:**
- Replace Teensy 4.0 with **Pico** (PIO cap-sense) or **ESP32-S3** (native touch)?
- Teensy 4.0 is over-spec'd for 11 pads
- Freeing it up enables many-pad experiments

**Related:** [[Architecture decision: board consolidation]]

**Next Steps:**
- [ ] Decide: Pico or ESP32 replacement?
- [ ] If Pico: procure resistors, test cap-sense
- [ ] If ESP32: validate native touch on 11 pads
- [ ] Free Teensy 4.0 for many-pad experiments

**Notes:**
- Pico fits 11-pad easily with PIO cap-sense
- ESP32-S3 also viable but overkill
- Simpler board = simpler firmware maintenance

---

### Printed Wooden 12-Pad + Screen — Board & Screen Integration
**Status:** Awaiting architecture decision

**Decision Points:**
1. Which board (Teensy, Pico, ESP32)?
2. How to fit 1.28" screen into wooden enclosure?

**Current Blockers:**
- Architecture decision (board allocation)
- Screen mechanical integration (CAD needed)

**Next Steps:**
- [ ] Finalize board consolidation decision
- [ ] Sketch screen mounting options
- [ ] CAD mechanical fit
- [ ] Route I2C/SDA/SCL wiring
- [ ] Prototype fit check

---

### ESP32-S3 Native Touch Design — 13-Pad Variant
**Decision Point:** Use on-chip 14-channel cap-sensing instead of MPR121?

**Proposed Allocation:**
- **ESP32-S3** (native touch) → Black 13-pad (replaces Pico)
- **Pico** (PIO cap-sense) → Black 11-pad (replaces Teensy 4.0)
- **Teensy 4.0** → freed for many-pad experiments

**Rationale:**
- ESP32-S3 has 14 on-die channels (eliminate MPR121 for lower pad counts)
- Pico proven PIO cap-sense works well
- Teensy 4.0 = highest-performance board for high-pad testbed

**Subtasks:**
- [ ] Validate ESP32-S3 native touch on 13 pads
- [ ] Tune CDC/CDT (different params vs MPR121)
- [ ] Create variant: `esp32s3-13pad-native-touch`
- [ ] Compare responsiveness: Pico vs native touch vs MPR121
- [ ] Decide if 19-pad switches to native (14-channel ceiling)

**Related:** [[Architecture decision: board consolidation]]

---

## 🧪 Experimental Epics (Waiting on Board Decision)

### EPIC: Pico Capacitive Sensing Tuning
**Instruments:** Black 13-pad (primary), Textured white (secondary)  
**Current Status:** 🔌 Hardware pending (resistors ordered)

**Overview:** Perfecting bare-pin PIO-based cap-sense (no MPR121). Proven "keeper" design: Mode 3 PIO guarded scan. Target: validate across shells + compare vs MPR121 + ESP32-S3 native.

**Subtasks:**
- [ ] Procure resistors (~1M, exact TBD)
- [ ] Install in black-13pad, tune CDC/CDT
- [ ] Test on textured white surface
- [ ] Measure latency vs MPR121 baseline
- [ ] Measure latency vs ESP32-S3 native
- [ ] Document tuning constants (config.h)

**Memory Reference:** [[Pico PIO capsense]] — Mode 3 PIO guarded scan proven

---

### EPIC: ESP32-S3 Native Touch Sensing
**Instruments:** Black 13-pad (primary), White 19-pad (secondary)  
**Current Status:** Design phase (blocked by architecture decision)

**Overview:** On-chip 14-channel capacitive sensing. Eliminates MPR121 for lower pad counts; simpler wiring + firmware.

**Subtasks:**
- [ ] Validate native touch on 13 pads (black-13pad)
- [ ] Tune CDC/CDT (different parameters vs MPR121)
- [ ] Measure latency + consistency
- [ ] Create variant: `esp32s3-13pad-native-touch`
- [ ] Compare vs Pico cap-sense vs MPR121
- [ ] Decide if 19-pad switches (14-channel ceiling)

**Memory Reference:** [[ESP32-S3 T8-S3 bring-up]]

---

### EPIC: Many-Pad MPR121 Experimental Version
**Instruments:** Teensy 4.0 (repurposed after board consolidation)  
**Current Status:** Planned (blocked by architecture decision)

**Overview:** High-pad-count testbed using 2–4 MPR121 boards on one I²C bus. Determine practical pad ceiling + firmware complexity.

**Subtasks:**
- [ ] Finalize board consolidation (frees Teensy 4.0)
- [ ] Design firmware for multi-chip MPR121 (2 chips = 24+ pads)
- [ ] Test I²C scanning latency with 2 chips
- [ ] Scale to 3 chips (36+ pads) if feasible
- [ ] Profile CPU + scanning performance
- [ ] Document scanning strategy (SENSE_PERIOD_MS, I²C clock, addressing)
- [ ] CAD shell design for many-pad layout
- [ ] Evaluate synth polyphony limits (can handle 24+ voices?)

**Memory Reference:** [[Teensy12 I2C ceiling]] — 100 kHz max with long wires + bus capacitance

---

### EPIC: Speaker Design
**Instruments:** Teensy 3.2 + Shield (primary), ESP32 Audio Kit (secondary)  
**Current Status:** Early (design phase)

**Overview:** Integrated speaker options for natural, resonant output. Explore driver matching + enclosure tuning.

**Subtasks:**
- [ ] Research driver impedance + power amp matching
- [ ] Sketch enclosure designs (ported vs sealed)
- [ ] Test acoustic principles (bass response, resonance)
- [ ] CAD enclosure for Teensy 3.2 + Shield
- [ ] CAD enclosure for ESP32 Audio Kit
- [ ] Prototype + measure frequency response

**Goal:** Warm, organic, acoustic-like sound (not high-fidelity). Small form factor (2–4" drivers).

---

### EPIC: Hang Drum Sound Design (Cross-All)
**Instruments:** Bamboo 12-pad (primary), White 19-pad (secondary), ESP32 Audio Kit (granular variant), all others benefit  
**Current Status:** Early (harmonic journey in progress on Bamboo)

**Overview:** Rich, resonant physical modeling synth capturing hang drum aesthetic. Warm, long sustains, modal resonance—not just wavetables.

**Subtasks:**
- [ ] Refine "harmonic journey" on Bamboo (current in-progress)
- [ ] Test harmonic journey on White 19-pad
- [ ] Explore sample-based modal synthesis (granular on Audio Kit)
- [ ] Design envelope shaping for hang drum sustain (slow release, no zipper)
- [ ] Experiment with layered wavetables (saw + filtered noise for shimmer)
- [ ] Record/analyze real hang drum for harmonic content
- [ ] Implement touch-responsive timbre morphing (brightness/decay with pressure)
- [ ] Build timbre library: "warm hang", "bright hang", "metallic hang"

**Audio Reference:**
- Physical modeling: Karplus-Strong (plucked strings), modal resonators
- Inspiration: Hang, steel tongue drum, vibraphone
- Techniques: Wavetable morphing, FM, granular synthesis, convolution

**Notes:**
- Hang drum sustain is very long (3–10 sec); CPU cost of tails is real
- Touch = brightness/attack (more expressive than volume)
- Natural sounding = avoid aliasing (interpolation in wavetables) + soft limiting (polyphonic peaks)

---

## ✅ Done

(Track completions here as tasks finish)

---

## Quick Status Summary

| Instrument | Status | Board | Pads | Epics | Key Task |
|---|---|---|---|---|---|
| 🎋 Bamboo 12-pad | 🔥 In Prog | Teensy 4.0 | 12 | Hang drum | Harmonic journey |
| ⚫ Black 11-pad | ⏸ Backlog | Teensy 4.0 | 11 | — | Board decision |
| ⚫ Black 13-pad | 📋 Todo | Pico | 13 | Pico cap-sense | Get resistors |
| ⚪ White 7-pad | 📋 Todo | Teensy LC | 7 | — | Test LEDs |
| ⚪ White 19-pad | 📋 Todo | ESP32-S3 | 19 | Hang drum | Sound design |
| 🎵 ESP32 Audio Kit | 📋 Todo | ESP32-S3 | ? | Hang drum, Speaker | Granular voices |
| ✨ Textured white | 📋 Todo | Pico | 13 | Pico cap-sense | Cap-sense + screen? |
| 🛡️ Teensy 3.2+Shield | 📋 Todo | Teensy 3.2 | 13 | Speaker | Enclosure CAD |
| 🪵 Printed wooden 12-pad | ⏸ Backlog | TBD | 12 | — | Board + screen |

---

## How to Use

**Daily work:** Scan "In Progress" + "Todo" sections for your current tasks.

**Check per-instrument status:** Find the instrument name (e.g., "Bamboo 12-Pad") to see:
- Board + pad count
- Current work
- Build commands
- Next steps
- Related code links

**Follow an experimental line:** Search for "EPIC:" to find multi-instrument initiatives (speaker design, hang drum sound, cap-sense tuning).

**Make progress:** Move tasks between sections (In Progress → Todo → Backlog), edit status notes.

**Add links:** Use `[text](path)` for code, memory refs as `[[name]]`.

---

## Legend

- 🔥 In Progress — actively being worked on
- 📋 Todo — ready to start
- ⏸ Backlog — waiting on decision or dependency
- ✅ Done — completed
- 🔌 Note marker — specific blocker or resource (e.g., "resistors ordered")
- (HIGH/MEDIUM/LOW) — priority when noted
- Memory ref: `[[name]]` — links to auto-memory from prior sessions

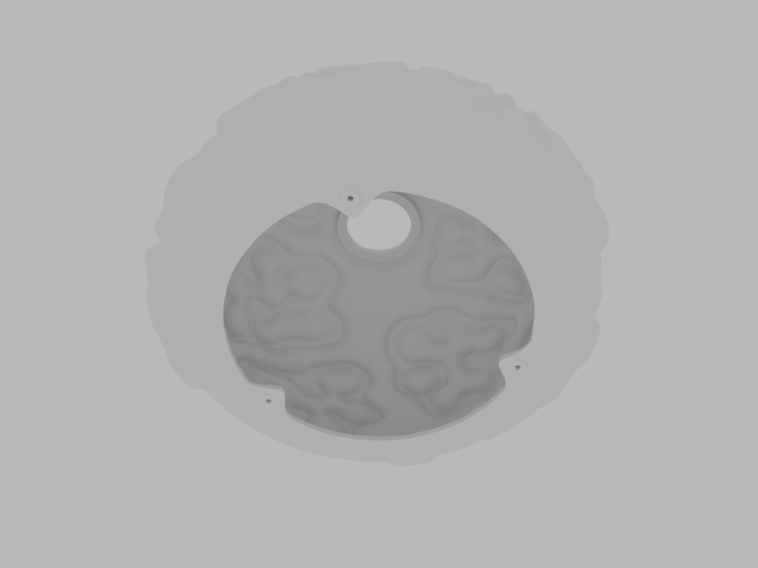
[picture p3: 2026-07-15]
3d-model/blender/preview_shell_bottom.png

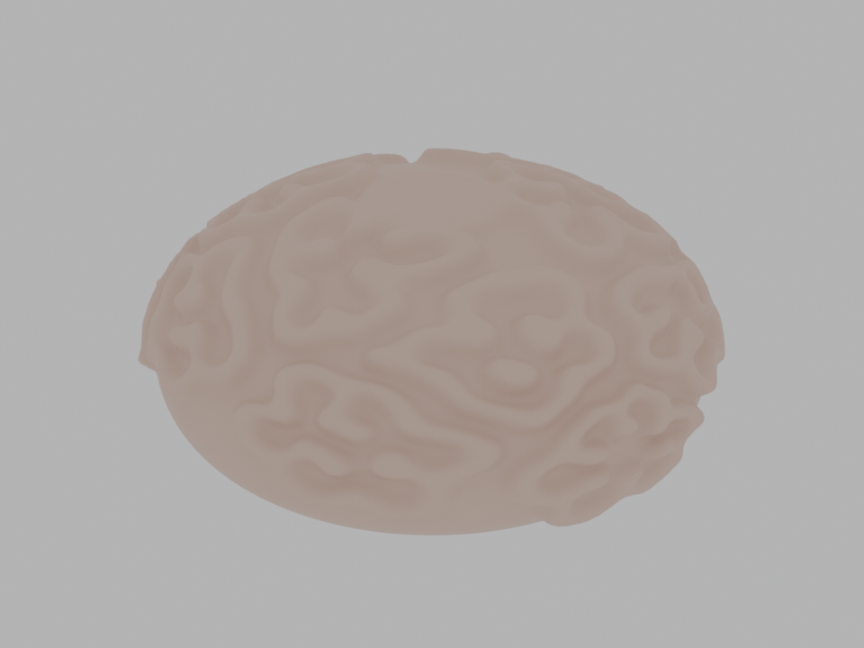
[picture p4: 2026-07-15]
3d-model/blender/preview.png

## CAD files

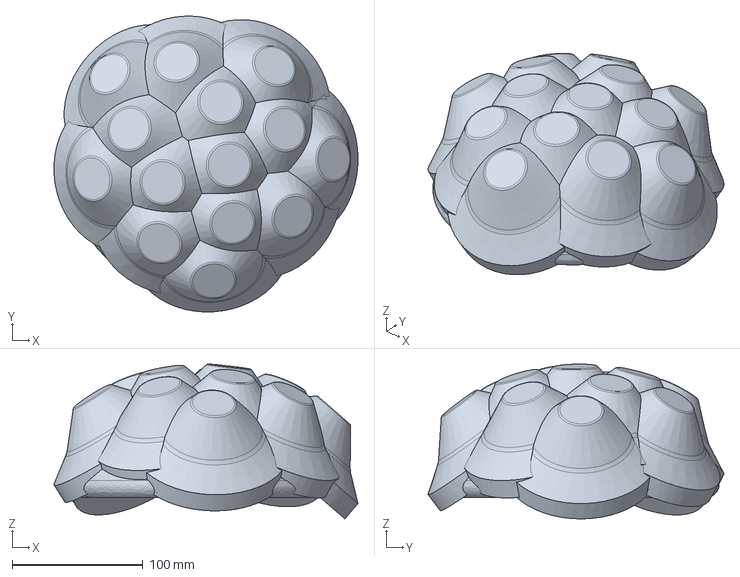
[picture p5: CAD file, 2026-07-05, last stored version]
3d-model/13 pad+screen in pad idea/thistle.step
233.0 x 226.7 x 118.7 mm

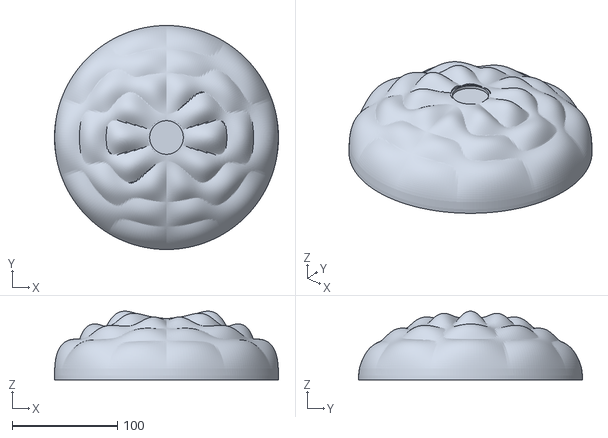
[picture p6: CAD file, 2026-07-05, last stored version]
3d-model/cymatics.stl
213.0 x 213.0 x 65.3

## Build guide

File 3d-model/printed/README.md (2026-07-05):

# Printed models — reference archive

This folder is the record of models that were **actually physically printed**.
Unlike the loose `.stl`/`.step` exports elsewhere in `3d-model/` (which are
git-ignored because they're large and regenerable from the `.py` scripts), the
contents of *this* folder **are committed** — they're the source of truth for
"what did I print, how did it come out, and with what settings."

## How to add a print

1. Copy the template folder and rename it for your print:

   ```bash
   cp -r "3d-model/printed/_template" "3d-model/printed/2026-07-05_thistle-lloyd"
   ```

   Suggested naming: `YYYY-MM-DD_<model-name>` (date you printed it).

2. Drop the exported mesh into the folder — the exact `.stl` (and/or `.step`)
   you sliced. These are un-ignored inside `printed/`, so they'll commit.

3. Add a photo (or several) of the finished print — `photo.jpg`, `photo-2.jpg`,
   etc. Any image format is fine.

4. Fill in `print-notes.md` with the slicer/printer settings and how it turned
   out.

## Creality slicer profiles

Exported Creality Print / Creality Slicer configuration profiles live in
`creality-profiles/`. Save reusable profiles there so a good print can be
reproduced exactly. See that folder's README for how to export them.

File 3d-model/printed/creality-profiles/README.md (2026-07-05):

# Creality slicer profiles

Save exported Creality print/slicer configuration profiles here so good prints
can be reproduced exactly.

## Exporting from Creality Print

- Open **Creality Print**.
- Set up your printer + print settings the way you want to keep them.
- In the print-settings panel, use the profile menu → **Export** (or
  right-click the profile → Export). This produces a config file (e.g.
  `.ini` / `.curaprofile` / `.creality_printer` depending on version).
- Drop the exported file in this folder and give it a descriptive name, e.g.
  `PLA_0.2mm_thistle.ini`.

Reference the profile name from a print's `print-notes.md` so it's clear which
profile produced which physical print.

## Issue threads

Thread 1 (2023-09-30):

Missing mounting holes on PCB

Somnitec, 2023-09-30:

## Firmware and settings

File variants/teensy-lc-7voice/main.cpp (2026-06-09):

// Teensy LC — 7-pad proximity synth with per-pad PWM LEDs + 3 WS2812 groups.
//
// Each of the 7 TSI touch pads drives (a) a sine voice whose level tracks
// proximity/press and (b) its own PWM indicator LED. Three addressable
// WS2812B LEDs each glow with the average proximity of the four pads nearest
// to them. Audio out via the LC's onboard 12-bit DAC on pin 26 (A12).
//
// ── Pin map (Teensy LC) ──────────────────────────────────────────────────────
//   Touch pads (TSI):  pad 0..6  -> pins 0, 1, 15, 16, 17, 18, 19
//   PWM LEDs:          pad 0..6  -> pins 3, 4, 6, 9, 10, 20, 22
//   WS2812 data:       pin 5     (WS2812Serial / DMA — audio-safe)
//   Audio out (DAC):   pin 26 (A12)  -> 100ohm -> 470uF(+ to DAC) -> jack/amp
//   WS2812 power:      VUSB (5V), common ground, ~330ohm on data
//
// Built to be flashed independently of the main firmware — see the
// `[env:lc_seven_voice]` block in platformio.ini.

#include <Audio.h>
#include <WS2812Serial.h>

// ── Diatonic note table (equal temperament, A4 = 440 Hz) ─────────────────────
namespace Note {
    static constexpr float C3  = 130.81f;
    static constexpr float E3  = 164.81f;
    static constexpr float G3  = 196.00f;
    static constexpr float B3  = 246.94f;
    static constexpr float C4  = 261.63f;
    static constexpr float E4  = 329.63f;
    static constexpr float G4  = 392.00f;
}

// ── Pad configuration ────────────────────────────────────────────────────────
// touchPin / pwmPin / freq are indexed by pad number 0..6. Pad 0 is the centre
// pad (it appears in all three WS2812 groups below). Rewire freely by editing
// these arrays — everything downstream follows the index.
static constexpr int   NVOICES = 7;
static constexpr int   touchPin[NVOICES] = {  19, 0,1,3,4,18,15 };
static constexpr int   pwmPin[NVOICES]   = {   20, 22, 6 , 9 , 10, 16 , 17 };
static constexpr float freq[NVOICES] = {
    Note::C3, Note::E3, Note::G3, Note::B3,   // Cmaj7
    Note::C4, Note::E4, Note::G4,             // upper octave
};

// ── Full-scale calibration (fraction of baseline) ────────────────────────────
// The touch-induced count change is ~proportional to the resting baseline (both
// scale with TSI gain), so a single FRACTION auto-tracks any NSCN/PS/REFCHRG
// retune — no recalibration when you change sensor settings. Volume hits 1.0 at
// baseline + baseline*TOUCH_FRACTION; firm plastic touch = full volume, bare
// metal spikes past and clamps at 1.0. Measure on the plotter: (touch−rest)/rest.
// Per-pad full-scale fraction (plastic-touch delta ÷ baseline), from the sweep:
//   pad   0     1     2     3     4     5      6
//   base  1987  2036  2094  2073  2040  2200   2394
//   Δ    ~160  ~135  ~124  ~133  ~135  noisy  ~50   (counts)
// Pads 0–4 are clean ~6–8%. Pad 6 (pin23) couples weakly (~2%) so it needs a
// small fraction to reach full. Pad 5 (pin19) is grounding-noisy (Δ≈noise) — no
// fraction fixes that; it needs the ground fix. Tune any entry to taste.
static constexpr float TOUCH_FRACTION[NVOICES] =
    { 0.065f, 0.065f, 0.065f, 0.065f, 0.065f, 0.065f, 0.065f };   // UNIFORM for the software/hardware test
static constexpr float REJECT_FRACTION = 0.20f;    // discard jumps > 20% of baseline (noise spikes)

// ── WS2812 groups ────────────────────────────────────────────────────────────
// Each addressable LED shows the average proximity of its four nearest pads.
static constexpr int    NLEDS = 3;
static constexpr int    LED_PIN = 5;
static constexpr uint8_t ledGroup[NLEDS][4] = {
    { 0, 1, 2, 3 },
    { 0, 3, 4, 5 },
    { 0, 5, 6, 1 },
};
// Group-average rise per LED tick (~33 ms) that maps to the FULL "fast" colour.
// Lower = fast colour triggers on a gentler approach; higher = only a quick jab.
static constexpr float SPEED_FULL_BLUE = 0.25f;

// LED colour endpoints (R,G,B 0..255), blended by approach speed and scaled by
// proximity. SLOW = resting/gentle-touch colour, FAST = quick-approach colour.
// Tune these freely — e.g. pink and purple instead of white and blue.
static constexpr uint8_t COLOR_SLOW[3] = { 255,  100,  200 };   // pink
static constexpr uint8_t COLOR_FAST[3] = { 150,   50, 255 };   // purple

byte ledDraw[NLEDS * 3];
DMAMEM byte ledDisp[NLEDS * 12];
WS2812Serial leds(NLEDS, ledDisp, ledDraw, LED_PIN, WS2812_GRB);  // WS2812B is GRB

// ── Per-sample interpolating gain ─────────────────────────────────────────────
// Ramps gain LINEARLY across every 128-sample block, so a gain change is a
// smooth slope, not a step at the block boundary — that block-boundary step is
// the amplitude "stair". Fixed-point; the M0+ multiply is single-cycle so 7 of
// these cost only a few % CPU. gain() is 0..1; set it from level[].
class AudioRampGain : public AudioStream {
public:
    AudioRampGain() : AudioStream(1, inputQueueArray), target(0), current(0) {}
    void gain(float g) {
        if (g < 0.0f) g = 0.0f; else if (g > 1.0f) g = 1.0f;
        target = (int32_t)(g * 65536.0f);
    }
    virtual void update(void) {
        audio_block_t *blk = receiveWritable();
        if (!blk) return;
        int32_t g = current;
        int32_t step = (target - current) / AUDIO_BLOCK_SAMPLES;
        for (int i = 0; i < AUDIO_BLOCK_SAMPLES; i++) {
            g += step;
            blk->data[i] = (int16_t)(((int32_t)blk->data[i] * g) >> 16);
        }
        current = target;
        transmit(blk);
        release(blk);
    }
private:
    audio_block_t *inputQueueArray[1];
    volatile int32_t target;
    int32_t current;
};

// ── Audio graph ──────────────────────────────────────────────────────────────
// sine (constant amplitude) → per-voice ramp gain → two stage mixers → master
// → DAC. Volume is the ramp gain (smooth), NOT the sine amplitude (which steps).
AudioSynthWaveformSine sine[NVOICES];
AudioRampGain          vgain[NVOICES];
AudioMixer4            stageMix[2];
AudioMixer4            masterMix;
AudioOutputAnalog      dac;

AudioConnection v0(sine[0], 0, vgain[0], 0);
AudioConnection v1(sine[1], 0, vgain[1], 0);
AudioConnection v2(sine[2], 0, vgain[2], 0);
AudioConnection v3(sine[3], 0, vgain[3], 0);
AudioConnection v4(sine[4], 0, vgain[4], 0);
AudioConnection v5(sine[5], 0, vgain[5], 0);
AudioConnection v6(sine[6], 0, vgain[6], 0);
AudioConnection c0(vgain[0], 0, stageMix[0], 0);
AudioConnection c1(vgain[1], 0, stageMix[0], 1);
AudioConnection c2(vgain[2], 0, stageMix[0], 2);
AudioConnection c3(vgain[3], 0, stageMix[0], 3);
AudioConnection c4(vgain[4], 0, stageMix[1], 0);
AudioConnection c5(vgain[5], 0, stageMix[1], 1);
AudioConnection c6(vgain[6], 0, stageMix[1], 2);
AudioConnection s0(stageMix[0], 0, masterMix, 0);
AudioConnection s1(stageMix[1], 0, masterMix, 1);
AudioConnection oD(masterMix, 0, dac, 0);

// ── Touch state ──────────────────────────────────────────────────────────────
int   baseline[NVOICES];
float level[NVOICES];        // smoothed output level per voice
float prevAvg[NLEDS];        // previous LED-group average (for approach speed)

// 7 voices × 0.12 ≈ 0.84 worst-case peak — headroom against in-phase clipping.
static constexpr float VOICE_AMP = 0.12f;

// Per-pad EMA smoothing (α at the 1 kHz control tick; higher = snappier). The
// per-sample gain ramp now removes clicks, so a smooth exponential glide here is
// ideal — it rounds the discrete sensor updates into a continuous volume contour
// (less "steppy") instead of the linear slew's straight-segment feel.
static constexpr float ATTACK[NVOICES]  = { 0.18f, 0.18f, 0.18f, 0.18f, 0.18f, 0.18f, 0.18f };
static constexpr float RELEASE[NVOICES] = { 0.08f, 0.08f, 0.08f, 0.08f, 0.08f, 0.08f, 0.08f };
static constexpr float GATE[NVOICES]    = { 0.10f,  0.10f,  0.10f,  0.10f,  0.10f,  0.10f,  0.10f };

// Per-pad enable. Pad 5 (pin19) false-triggers from grounding noise the stopgap
// can't tame — muted for now. Set its entry back to 1 once its wiring/ground is
// fixed (pin18 on the same side is clean, so suspect pin19's specific lead).
static constexpr bool PAD_ENABLED[NVOICES] = { 1, 1, 1, 1, 1, 1, 1 };

// Onboard LED (pin 13): fast blink during setup, slow blink while running.
static constexpr int   STATUS_LED    = 13;
// Temporal median window: median of the last N reads PER PAD over time. Rejects
// single-sample glitches for the cost of just ONE TSI read per loop — spatial
// oversampling (N reads every loop) is what made it slow. Odd values: 3, 5.
static constexpr int   MEDIAN_WIN = 5;   // catches spikes up to 2 samples wide with no lag

// Spike rejector: hold the last accepted value through any read that jumps more
// than baseline*REJECT_FRACTION (transient grounding noise), but after MAX_REJECT
// consecutive rejects accept anyway so a genuinely sustained change gets through.
static constexpr int   MAX_REJECT  = 8;

// 1 = stream raw TSI counts (tab-separated, Arduino Serial-Plotter friendly)
// for calibration; 0 = print the CPU/memory status line instead.
#define CALIBRATE 0

// 1 = drive the per-pad PWM LEDs. Set 0 to TEST whether PWM switching on pins
// physically adjacent to the touch pins (15↔16, 17↔18, 19↔20) is what couples
// noise into pads 0/5/6. If turning this off makes them clean → confirmed.
#define ENABLE_PWM 0

// ⚠ Teensy LC: AudioOutputAnalog commandeers FTM1 (pins 3 & 4) for its 44 kHz
// sample clock. So: do NOT use pins 3/4 for PWM, and do NOT call
// analogWriteFrequency() — touching an FTM can kill the audio clock (silence).
// PWM stays at the default frequency; coupling is handled by pin PLACEMENT.

// ── TSI backend ──────────────────────────────────────────────────────────────
// 0 = Teensy's stock touchRead() (REFCHRG4/EXTCHRG3/PS2/NSCN9).
// 1 = our own tsiRead() using the fields below. Same scan sequence as the core
// (see cores/teensy3/touch.c), just with knobs exposed for max range/resolution:
//   • higher NSCN  → more scans accumulated → bigger counts (more resolution)
//   • higher PS    → longer count window     → bigger counts (slower scan)
//   • lower EXTCHRG→ slower electrode osc     → more counts per ΔC (sensitivity)
// If the raw stream rails at 65535 (16-bit overflow), back off PS then NSCN.
#define USE_CUSTOM_TSI 1
// Scan time ≈ (NSCN+1) × 2^PS reference periods — big values mean high
// resolution but SLOW reads, which makes the loop crawl and the audio step.
// Keep their product modest; prefer raising NSCN over PS.
// A/B test result: noise was our aggressive EXTCHRG=1/DVOLT=1, NOT the ISR.
// Keep EXTCHRG=3/DVOLT=0 (robust), but raise NSCN for range — more scans = bigger
// counts AND fewer interrupts (slower scans → less audio jitter/dithering).
static constexpr int TSI_NSCN_FIELD    = 31;  // 32 scans — span/SNR + lowest ISR rate (9 = too few counts, flickers)
static constexpr int TSI_PS_FIELD      = 2;
static constexpr int TSI_EXTCHRG_FIELD = 3;   // keep robust (1 = max sensitivity AND max noise)
static constexpr int TSI_REFCHRG_FIELD = 4;
// ΔV hysteresis (0..3). Datasheet trick: the COUNT is independent of ΔV (it
// cancels in the electrode/reference frequency ratio) but the scan TIME ∝ ΔV.
// So raising this speeds up reads with NO recalibration: 0=1.03V (slowest),
// 1=0.59V (~1.7×), 2=0.34V (~3×), 3=0.20V (~5×). Higher = faster but noisier.
static constexpr int TSI_DVOLT_FIELD   = 0;   // was 1 (matches stock for the A/B test)

int  rawNow[NVOICES];                 // filtered count per pad (for the dump)
int  rawHist[NVOICES][MEDIAN_WIN];    // recent raw reads for the temporal median
int  lastGood[NVOICES];               // last accepted raw per pad (spike rejector)
int  rejectRun[NVOICES];              // consecutive rejections per pad
int  touchSpan[NVOICES];              // baseline*TOUCH_FRACTION  (full-scale count span)
int  rejThresh[NVOICES];              // baseline*REJECT_FRACTION (spike-reject threshold)
unsigned long loopCount = 0;          // loops since last status print (loop-rate diag)
bool blinkState = false;
elapsedMillis sinceLED;
elapsedMillis sinceStatus;
elapsedMillis sinceBlink;
elapsedMillis sinceRaw;
elapsedMicros  sinceCtrl;     // fixed-rate control tick (regular amplitude updates = less zipper)

// ── TSI background scanner ───────────────────────────────────────────────────
#if USE_CUSTOM_TSI
// Pin → TSI channel for Teensy LC (MKL26Z64), from the core's touch.c pin2tsi[].
static const uint8_t pin2tsiLC[] = {
      9, 10, 255,   2,   3, 255, 255, 255, 255, 255,
    255, 255, 255, 255, 255,  13,   0,   6,   8,   7,
    255, 255,  14,  15, 255, 255, 255
};

// Scan ORDER (pad indices). Interleaving physically-distant pads means a touched
// pad never lands right before its neighbour, so any residual carry-over hits an
// unrelated pad instead of the adjacent one. Must be a permutation of 0..NVOICES-1.
static constexpr uint8_t scanOrder[NVOICES] = { 0, 2, 5, 3, 6, 4, 1 };
// Discarded "settle" scans after each channel switch (flush the previous
// channel's charge from the shared front-end). Raise if a touch still bleeds.
static constexpr int     SETTLE_SCANS = 2;

volatile uint16_t rawScan[NVOICES];   // latest count per pad, written by the ISR
volatile uint8_t  scanPos = 0;        // index into scanOrder[]
volatile int      settleLeft = SETTLE_SCANS;
uint8_t           scanCh[NVOICES];    // TSI channel per pad (precomputed)

// End-of-scan interrupt. For each channel we discard SETTLE_SCANS priming reads
// (so the previous channel can't bleed in — the pad-to-pad crosstalk), then keep
// the next one. Scans follow scanOrder[] so neighbours aren't adjacent in time.
void tsi0_isr(void) {
    uint8_t  pad   = scanOrder[scanPos];
    uint16_t count = TSI0_DATA & 0xFFFF;              // read count BEFORE clearing EOSF
    TSI0_GENCS |= TSI_GENCS_EOSF;                     // clear end-of-scan flag (w1c)
    if (settleLeft > 0) {
        settleLeft--;                                 // discard this priming scan
    } else {
        rawScan[pad] = count;                         // clean read
        scanPos = (scanPos + 1) % NVOICES;            // advance to next pad in the order
        settleLeft = SETTLE_SCANS;
        pad = scanOrder[scanPos];
    }
    TSI0_DATA = TSI_DATA_TSICH(scanCh[pad]) | TSI_DATA_SWTS;
}

// Configure TSI for continuous, interrupt-driven scanning of all pads.
static void startTsiScanner() {
    SIM_SCGC5 |= SIM_SCGC5_TSI;
    for (int i = 0; i < NVOICES; i++) {
        *portConfigRegister(touchPin[i]) = PORT_PCR_MUX(0);
        scanCh[i] = pin2tsiLC[touchPin[i]];
    }
    TSI0_GENCS = TSI_GENCS_REFCHRG(TSI_REFCHRG_FIELD)
               | TSI_GENCS_EXTCHRG(TSI_EXTCHRG_FIELD)
               | TSI_GENCS_DVOLT(TSI_DVOLT_FIELD)
               | TSI_GENCS_PS(TSI_PS_FIELD)
               | TSI_GENCS_NSCN(TSI_NSCN_FIELD)
               | TSI_GENCS_TSIEN | TSI_GENCS_TSIIEN | TSI_GENCS_ESOR;
    NVIC_SET_PRIORITY(IRQ_TSI, 255);   // lowest priority — never preempt the audio update
    NVIC_ENABLE_IRQ(IRQ_TSI);
    scanPos = 0;
    settleLeft = SETTLE_SCANS;
    TSI0_DATA = TSI_DATA_TSICH(scanCh[scanOrder[0]]) | TSI_DATA_SWTS;   // kick off the chain
}
#endif

// Latest raw count for pad i, from whichever backend is active.
static inline int readPadIdx(int i) {
#if USE_CUSTOM_TSI
    return rawScan[i];                 // cached by the background ISR — never blocks
#else
    return touchRead(touchPin[i]);     // stock: blocking read each call
#endif
}

// Median of a small sample set (insertion sort — n is tiny). Unlike a mean,
// this fully rejects a single outlier sample (the glitch noise we're seeing).
static int medianOfN(int *a, int n) {
    for (int i = 1; i < n; i++) {
        int key = a[i], j = i - 1;
        while (j >= 0 && a[j] > key) { a[j + 1] = a[j]; j--; }
        a[j + 1] = key;
    }
    return a[n / 2];
}

// Smoothly fade all WS2812s (white) from one brightness to another over durMs.
static void fadeLeds(int from, int to, int durMs) {
    const int steps = 24;
    for (int s = 0; s <= steps; s++) {
        int v = from + (to - from) * s / steps;
        for (int g = 0; g < NLEDS; g++) leds.setPixel(g, v, v, v);
        leds.show();
        delay(durMs / steps);
    }
}

void setup() {
    Serial.begin(115200);
    AudioMemory(8);
    leds.begin();
    //pinMode(STATUS_LED, OUTPUT);

    /*
    // Colour-order check: should flash RED, then GREEN, then BLUE in turn.
    // If the order is wrong, change WS2812_GRB above to match what you see.
    const uint8_t probe[3][3] = { {120, 0, 0}, {0, 120, 0}, {0, 0, 120} };
    for (int c = 0; c < 3; c++) {
        for (int g = 0; g < NLEDS; g++) leds.setPixel(g, probe[c][0], probe[c][1], probe[c][2]);
        leds.show();
        delay(400);
    }
*/
    for (int i = 0; i < NVOICES; i++) {
        sine[i].frequency(freq[i]);
        sine[i].amplitude(VOICE_AMP);   // constant; volume is the smooth ramp gain
        vgain[i].gain(0.0f);
        pinMode(pwmPin[i], OUTPUT);
        analogWrite(pwmPin[i], 0);
    }

#if USE_CUSTOM_TSI
    startTsiScanner();        // begin continuous background scanning
    delay(100);               // let every pad get scanned a few times first
#endif

    // Fade the LEDs up while calibrating (a visible "booting" cue)...
    fadeLeds(0, 160, 600);

    // Sample the baseline from the (now background-scanned) counts.
    Serial.println("Calibrating baseline. Do NOT touch the pads...");
    delay(300);
    for (int i = 0; i < NVOICES; i++) {
        long sum = 0;
        for (int n = 0; n < 32; n++) { sum += readPadIdx(i); delay(5); }
        baseline[i]  = sum / 32;
        level[i]     = 0.0f;
        lastGood[i]  = baseline[i];
        rejectRun[i] = 0;
        touchSpan[i] = (int)(baseline[i] * TOUCH_FRACTION[i]);
        rejThresh[i] = (int)(baseline[i] * REJECT_FRACTION);
        for (int k = 0; k < MEDIAN_WIN; k++) rawHist[i][k] = baseline[i];
    }

    // ...then fade off — calibration done, ready to play.
    fadeLeds(160, 0, 600);
    Serial.println("Baseline set. Ready.");
}

void loop() {
    loopCount++;

    // ── Control tick: process pads + update audio at a STEADY 1 kHz ──────────
    // Doing this every (jittery) loop pass made amplitude steps land unevenly →
    // zipper. A fixed cadence makes the steps regular and quiet. Reads are free
    // (the ISR scans in hardware), so this only paces the math + amplitude write.
    if (sinceCtrl >= 1000) {
    sinceCtrl -= 1000;
    for (int i = 0; i < NVOICES; i++) {
        int raw = readPadIdx(i);

        // Spike rejector: hold the last good value through implausible jumps.
        int dev = raw - lastGood[i];
        if (dev < 0) dev = -dev;
        if (dev > rejThresh[i] && rejectRun[i] < MAX_REJECT) {
            raw = lastGood[i];
            rejectRun[i]++;
        } else {
            lastGood[i]  = raw;
            rejectRun[i] = 0;
        }

        for (int k = MEDIAN_WIN - 1; k > 0; k--) rawHist[i][k] = rawHist[i][k - 1];
        rawHist[i][0] = raw;
        int tmp[MEDIAN_WIN];
        for (int k = 0; k < MEDIAN_WIN; k++) tmp[k] = rawHist[i][k];
        int med = medianOfN(tmp, MEDIAN_WIN);
        rawNow[i] = med;

        // baseline + touchSpan maps to 1.0; a metal spike past that clamps here.
        float t = (med - baseline[i]) / (float)touchSpan[i];
        if (t < 0.0f) t = 0.0f;
        if (t > 1.0f) t = 1.0f;     // plastic = full scale; metal can't push further
        if (t < GATE[i]) t = 0.0f;
        if (!PAD_ENABLED[i]) t = 0.0f;   // muted pads stay silent

        // EMA glide toward target (smooth exponential). Clicks are handled by the
        // per-sample gain ramp, so this just shapes a continuous volume contour.
        float a = (t > level[i]) ? ATTACK[i] : RELEASE[i];
        level[i] += (t - level[i]) * a;
        vgain[i].gain(level[i]);   // per-sample-interpolated → click-free
#if ENABLE_PWM
        analogWrite(pwmPin[i], (int)(level[i] * 255.0f));
#endif
    }
    }  // end 1 kHz control tick

    // ── WS2812 groups: average of four nearest pads, throttled to ~30 Hz ─────
    if (sinceLED >= 33) {
        sinceLED = 0;
        for (int g = 0; g < NLEDS; g++) {
            float avg = 0.0f;
            for (int k = 0; k < 4; k++) avg += level[ledGroup[g][k]];
            avg *= 0.25f;

            // Approach speed = how fast the group average rose since last tick.
            // Approach speed blends SLOW→FAST colour; brightness = proximity.
            float s = (avg - prevAvg[g]) / SPEED_FULL_BLUE;
            prevAvg[g] = avg;
            if (s < 0.0f) s = 0.0f;
            if (s > 1.0f) s = 1.0f;

            int r  = (int)(avg * ((1.0f - s) * COLOR_SLOW[0] + s * COLOR_FAST[0]));
            int gr = (int)(avg * ((1.0f - s) * COLOR_SLOW[1] + s * COLOR_FAST[1]));
            int b  = (int)(avg * ((1.0f - s) * COLOR_SLOW[2] + s * COLOR_FAST[2]));
            leds.setPixel(g, r, gr, b);
        }
        leds.show();
    }
/*
    // ── Status LED: slow blink (~1 Hz) while running ─────────────────────────
    if (sinceBlink >= 500) {
        sinceBlink = 0;
        blinkState = !blinkState;
        digitalWrite(STATUS_LED, blinkState);
    }
*/
#if CALIBRATE
    // ── Per pad: raw count then the final smoothed level (0..1) that drives the
    //    sine amplitude and feeds the LED groups. Tab-separated: raw0 lvl0 raw1 lvl1 …
    if (sinceRaw >= 100) {
        sinceRaw = 0;
        for (int i = 0; i < NVOICES; i++) {
            Serial.print(rawNow[i]);   Serial.print('\t');
            Serial.print(level[i], 2); Serial.print('\t');
        }
        Serial.println();
    }
#else
    // ── Status (no printf %f — the LC can't format floats that way) ──────────
    if (sinceStatus >= 2000) {
        Serial.print("loop Hz: ");
        Serial.print(loopCount / 2);                 // loops/sec over the 2s window
        Serial.print("   CPU max %: ");
        Serial.print(AudioProcessorUsageMax(), 1);
        Serial.print("   audio blocks max: ");
        Serial.println(AudioMemoryUsageMax());
        loopCount   = 0;
        sinceStatus = 0;
    }
#endif
}

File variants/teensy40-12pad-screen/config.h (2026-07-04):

#pragma once
#include <stdint.h>
#include <Audio.h> // for WAVEFORM_* constants

// ─────────────────────────────────────────────────────────────────────────────
// Instrument configuration
//
// Edit this file to match your physical wiring and musical preferences.
// The rest of the firmware reads from SENSORS[], SCALE_SETS[], TIMBRE_SETS[],
// and the synth parameter constants — no other files need to change when you
// remap pads, retune frequencies, or add new scales/timbres.
// ─────────────────────────────────────────────────────────────────────────────

// ── Board setup ──────────────────────────────────────────────────────────────
static constexpr uint8_t NUM_BOARDS        = 2;
static constexpr uint8_t BOARD_ADDRESSES[] = { 0x5D, 0x5B, 0x00, 0x00 };

// Set to 1 only if a round LCD/touch screen is attached. 0 skips all LCD and
// touchscreen init (and the GUI draws) — noticeably faster startup.
// This is the 12-pad + screen build, so it ships ON. (All screen code is
// isolated in display.h; flipping this to 0 turns every display*() call into
// a no-op.)
#define ENABLE_SCREEN 1

// Serial diagnostics. The periodic 10 Hz readout streams over USB constantly,
// and that USB bus activity can couple a faint high-pitched whine into the
// PCM5102A audio. Keep at 0 for silent running; set to 1 only when you need the
// live per-pad / CPU readout. (Startup banner + sound-change lines still print.)
#define SERIAL_DEBUG 0

// ── Sensor descriptor ────────────────────────────────────────────────────────
static constexpr uint8_t NO_PIN = 0xFF; // disabled pad / no LED

// ledBoard sentinel: the LED is wired straight to a Teensy GPIO pin (PWM), not
// to an MPR121 LED driver. Use this to escape the chip's flaky ELE9/ELE10
// drivers — set ledBoard = LED_TEENSY and put the Teensy pin number in ledEle.
static constexpr uint8_t LED_TEENSY = 0xFE;

struct SensorConfig {
    uint8_t boardIndex; // SENSE board: index into BOARD_ADDRESSES[]
    uint8_t electrode;  // ELE0–ELE5 touch input, or NO_PIN if this pad is disabled
    uint8_t ledBoard;   // LED board index, or LED_TEENSY for a direct Teensy GPIO LED
    uint8_t ledEle;     // MPR121 LED pin (ELE6–ELE11), OR a Teensy pin # when
                        // ledBoard == LED_TEENSY, or NO_PIN if no LED
};

// Touch electrodes per board, indexed by board. ELE_EN is a contiguous count
// from ELE0, so to sense ELE6 the chip must enable ELE0–ELE6 (7 electrodes).
//   • Board A (idx 0, 0x5D) = 7: senses ELE0–ELE6. The bust A-ELE0 is
//     abandoned; pad 6 relocated to A-ELE6. A-ELE6 is a sense electrode, so the
//     chip won't drive an LED on it → pad 6's LED is on Teensy GPIO instead.
//   • Board C (idx 1, 0x5B) = 6: senses ELE0–ELE5 only, leaving ELE6 free as a
//     GPIO/LED pin — that's where pad 0's LED lives.
// GOTCHA (this exact bug bit us): the MPR121 ignores GPIO/LED on any
// sense-enabled electrode. If you ever bump board C to 7, pad 0's LED on
// C-ELE6 goes dark — move that LED to Teensy first.
static constexpr uint8_t SENSE_ELECTRODES[NUM_BOARDS] = { 7, 6 };

// MPR121 charge current / time (sensor gain). Controlled measurement
// (test/proximity_tuning) shows the electrode does NOT couple beyond ~1 cm at
// ANY CDC — this is a near-field/touch instrument, not a distance theremin
// (electrode geometry limit, not firmware). Within the usable zone
// (~1 cm → plastic → metal) CDC=16 gave the strongest, cleanest spread with
// idle noise still ~1 (1 cm/plastic ≈ 5/22 vs 3/14 at CDC=10). CDC=48 was
// over-saturated and felt dead — 16 is the measured sweet spot, not extreme.
static constexpr uint8_t SENSOR_CDC = 14; // 0–63 (try 10 to A/B; both 1 line)
static constexpr uint8_t SENSOR_CDT = 3;  // 0–7  (ESI stays 2 ms → flicker-free LEDs)

// First-filter iterations: 0–3 → 6/10/18/34 samples averaged per measurement.
// More averaging = lower idle-noise floor at the SAME output rate, which is
// what lets the deadband sit lower = more proximity reach. Bench-measured
// (sensor_characterization FFI sweep, 2 s per value): FFI=0 → idle wobble up
// to 2 counts (std 0.25); FFI≥1 → dead flat, zero deviation over 2298 samples.
// 1 (=10 samples) is the sweet spot; higher showed no further gain.
static constexpr uint8_t SENSOR_FFI = 1;

// Electrode sample interval: 2^ESI ms. The chip's filtered output updates
// every SFI×ESI = 4×2^ESI ms, so ESI=1 (2 ms) → new data every 8 ms, ESI=0
// (1 ms) → every 4 ms. Bench capture showed the release tail is mostly this
// chip-side filter (~6 output frames to settle), so halving the cadence
// halves both attack and release lag at the source. REVERT TO 1 IF the
// MPR121-driven LEDs (pads 0,1,2,5,7,8,11) visibly flicker — the old comment
// claimed ESI=2 ms mattered for that, never verified with data.
static constexpr uint8_t SENSOR_ESI = 0;
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

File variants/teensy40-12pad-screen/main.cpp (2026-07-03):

#include <Arduino.h>
#include <Wire.h>
#include <Audio.h>
#include <EEPROM.h>
#include <math.h>

#include "config.h"
#include "display.h"   // all LCD/touch/GUI code (no-op when ENABLE_SCREEN == 0)
#include "proximity_engine.h"
#include "sound_engine.h"
#include "benjolin.h"    // Benjolin-mode chaos source
#include "cracklebox.h"  // Cracklebox-mode chaos source
#include "hangbow.h"     // Hang Bow mode: bowed handpan physical model
#include "swarm.h"       // Swarm mode: additive chime cloud
#include "grainsample.h" // Grain Hang mode: granular hang-drum sample
#include "strings.h"     // Strings mode: looped string-section sample
#include "bowls.h"       // Bowls mode: rubbed singing bowls
#include "tanpura.h"     // Tanpura mode: jawari drone strings
#include "flute.h"       // Flute mode: breath waveguide wind
#include "cello.h"       // Cello mode: bowed-string waveguide
#include "phasechimes.h" // Phase Chimes mode: generative phasing mallets
#include "freezer.h"     // Freeze mode: click-free windowed freeze layer
#include <MPR121.h>

// ─────────────────────────────────────────────────────────────────────────────
// Audio graph — Subtractive synth architecture
//
// 12 independent voices, each with:
//   mainOsc (triangle/saw) + subOsc (sine, -1 oct) -> voiceMix -> filter (LP)
//   -> ampGate (multiplied by dcAmp for click-free level control) -> stage mixer
//
// Three-stage mixer tree to stereo I2S output (PCM5102A DAC).
// ─────────────────────────────────────────────────────────────────────────────

// ── Voice instances ──────────────────────────────────────────────────────────
static Voice voices[NUM_SENSORS];

// ── Mixer tree ───────────────────────────────────────────────────────────────
AudioMixer4    stageMix[3];  // stage 1: up to 4 voices each
AudioMixer4    masterMix;    // stage 2: combines 3 stage mixers + bell on ch 3
AudioOutputI2S i2sOut;

// ── Bell — one touch-transient voice per pad ─────────────────────────────────
// One voice per pad (indexed by sensor) so several players striking different
// pads at once never steal each other. Each voice: two sine partials
// (fundamental + inharmonic) → fast envelope → 3-mixer tree → master ch 3.
static constexpr uint8_t NUM_BELLS = NUM_SENSORS;
static_assert(NUM_BELLS == 12, "BELL_WIRING below is hand-wired for 12 voices");

AudioSynthWaveformSine   bellOscA[NUM_BELLS];
AudioSynthWaveformSine   bellOscB[NUM_BELLS];
AudioMixer4              bellVoiceMix[NUM_BELLS];
AudioFilterStateVariable bellFilt[NUM_BELLS]; // per-voice LP for pressure aftertouch
AudioEffectEnvelope      bellEnv[NUM_BELLS];
AudioMixer4              bellGroup[3]; // 4+4+4 voices
AudioMixer4              bellSum;      // groups → master ch 3

#define BELL_WIRING(K, G, CH)                                                \
    AudioConnection bw##K##a(bellOscA[K],     0, bellVoiceMix[K], 0);        \
    AudioConnection bw##K##b(bellOscB[K],     0, bellVoiceMix[K], 1);        \
    AudioConnection bw##K##f(bellVoiceMix[K], 0, bellFilt[K],     0);        \
    AudioConnection bw##K##m(bellFilt[K],     0, bellEnv[K],      0);        \
    AudioConnection bw##K##e(bellEnv[K],      0, bellGroup[G],    CH);
BELL_WIRING( 0, 0, 0)
BELL_WIRING( 1, 0, 1)
BELL_WIRING( 2, 0, 2)
BELL_WIRING( 3, 0, 3)
BELL_WIRING( 4, 1, 0)
BELL_WIRING( 5, 1, 1)
BELL_WIRING( 6, 1, 2)
BELL_WIRING( 7, 1, 3)
BELL_WIRING( 8, 2, 0)
BELL_WIRING( 9, 2, 1)
BELL_WIRING(10, 2, 2)
BELL_WIRING(11, 2, 3)
AudioConnection bgs0(bellGroup[0], 0, bellSum, 0);
AudioConnection bgs1(bellGroup[1], 0, bellSum, 1);
AudioConnection bgs2(bellGroup[2], 0, bellSum, 2);
AudioConnection bellOut(bellSum, 0, masterMix, 3);

// ── Per-voice wiring (macro expands to 6 internal + 1 output connection) ─────
//                      voice index, stage mixer,  channel
VOICE_WIRING( 0, stageMix[0], 0)
VOICE_WIRING( 1, stageMix[0], 1)
VOICE_WIRING( 2, stageMix[0], 2)
VOICE_WIRING( 3, stageMix[0], 3)
VOICE_WIRING( 4, stageMix[1], 0)
VOICE_WIRING( 5, stageMix[1], 1)
VOICE_WIRING( 6, stageMix[1], 2)
VOICE_WIRING( 7, stageMix[1], 3)
VOICE_WIRING( 8, stageMix[2], 0)
VOICE_WIRING( 9, stageMix[2], 1)
VOICE_WIRING(10, stageMix[2], 2)
VOICE_WIRING(11, stageMix[2], 3)

// ── Mixer tree wiring ────────────────────────────────────────────────────────
AudioConnection pm0(stageMix[0], 0, masterMix, 0);
AudioConnection pm1(stageMix[1], 0, masterMix, 1);
AudioConnection pm2(stageMix[2], 0, masterMix, 2);
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

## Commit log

2023-09-30 Touch sensors functional
2023-10-12 two sensor boards
2026-03-12 main code reading mpr121 cap and blinking led
2026-03-19 included MPR121 into git. Note, there's some changes to the library to enable it to work with less sensors
2026-03-19 screen and two sensors functional
2026-03-29 claude changes, made pwm work and metal sensor calibration
2026-04-01 code is working on the big prototype
2026-04-01 added a sensor test
2026-04-03 corrected mistake in how the testproject is handled
    [raw_sensor_readout.cpp]
2026-05-15 New prototype, found some weirdness in the mpr121 but now all working
2026-05-21 Fixed some ambient glitch and made balanced output
    [config.h, main.cpp, proximity_engine.h]
2026-05-29 added sound set selection and better calibration
2026-06-01 added a teensy lc seven voice draft
2026-06-03 calibration tweaks
2026-06-09 7 pad version working with teensy LC, however the touch sensing bugs with PWM on the individual channels enabled, can consider to rewire and see if it's different, but for now only the internal leds 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
2026-06-09 Restructure into PlatformIO monorepo + bring up Pico 13-pad build
    Move each instrument into variants/<name>/ selected by its [env:...]
    build_src_filter; shared drivers stay in lib/, diagnostics in test/.
    Variants: pico-13pad (default), teensy40-11pad, teensy40-12pad-screen,
    teensy32-13pad, teensy-lc-7voice (+ esp32s3 scaffold).
    Pico 13-pad (RP2040 + 2x MPR121 + Mozzi + PCM5102A I2S):
    - Independent SCALE (even pad) x TIMBRE (odd pad) selection, held at boot
    or sent over serial as a pad number; persisted to EEPROM across resets.
    - 6 scales (Pentatonic, Cmaj7-JI, Overtones, Wide Dorian, Chromatic,
    Harmonic Minor) voiced low; stacked-thirds layouts keep adjacent-pad
    chords consonant. 6 ti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
    [config.h, display.h, main.cpp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]
2026-06-09 click when changing settings fixed
    [main_pico.cpp, sound_engine_mozzi.h]
2026-06-09 touch test works with the esp32 over wifi and also teleplot readout
2026-06-09 made pico PIO capsensing work, quite sensitive!
2026-06-09 confirmed esp32 battery sensor
2026-06-11 made it possible to lock the screen and small fixes
    [config.h, display.h, main.cpp]
2026-06-12 19 pin functional in its basics!
2026-06-12 some tweaks to the esp32 19 pad version
2026-06-25 added a kanban board
2026-06-26 esp32 audio kit granular synth working in the basics
2026-07-03 tonal map implemented, as well as calibration and screen tweaks
2026-07-03 end of session, calibration can still use some work
2026-07-03 Calibration and screen tweaked (no chord names) end of work session
2026-07-05 made 3d model generators
    [cymatics.stl, thistle.step]
2026-07-05 tweaks to the 3d generators
    [cymatics.stl, thistle.step]
